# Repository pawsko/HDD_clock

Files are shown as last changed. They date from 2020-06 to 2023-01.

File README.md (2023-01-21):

# My first embedded project #
## Introduction ##
Some time ago I saw an amazing clock based on HDD on Youtube. There was dedicated clock face made from original plate with drilled numbers
from 0 to 9 and colon sign. Under plate there were LEDs. Clock face was rotating very fast, exactly 5400RPM like regular HDD. LEDs were blinked
exectly right in time when right number was above right LED. I was thinking this project is perfect to replicate for my self and practise C programming:)
Clock which I saw had only hours and minutes. I wanted to go a step further and add seconds as well.

It took me some of time to figure out how to approach to this topic.
The easiest part for me was design hardware. I took broken HDD, removed all platters, measured their diameters and made a decision that there will be 
12 signs on PCB.
Why 12? because of dividing. 

360 degrees / 11 signs = 32.72727272.... degrees per sign

360 / 12 = 30 degrees per sign. Very nice.

I wasn't shure about shape of controller, so I split electronics to two part. Controller and LED driver. I planned to use evaluation board 
with FPGA or microcontroller on board and design only board with LED, power supply circuits and buttons. 
FPGA is obvoius for this solution but I have no knowledge and experience in this area.
## First version (prototype) ##
In first attempt I used NUCLEO-F103RB. Cheap and very popular evaluation board with STM32F103 microcontroller. I utylized there all counters. 
Each digit has own. One additional counter measures one complete revolution.
There is an interrupt for detect zero position of clock face.
Brushless motor controller was taken from HDD so it spinup motor only for 10 second and expected signal from magnetic heads (were removed). Additionally once per second reduced speed for a while.
Despite this it worked. After 10 seconds motor has stopped. Probably disk controller reported error to host (BIOS in PC).
There was some issue with synchronisation while colons were blinked.
## Second version ##
I integrated two parts of electronics to one board and I added Real Time Clock programmed through UART with backup battery, brushless motor controller,
button to change mode clock/callendar (last video). I changed soldermask from regular green to black (looks like dark brown).
## Opened issues ##
1. Unfortunatelly motor is noisy.
2. Contrast is insufficient during sunlight. LEDs are super bright but clock face builded from FR4 provides low light transmision. Second wersion with black solder mask is much more effective, but it's still not enough.
3. Clock face is unbalanced because of heteregenous material and digits. Reminder: 5400RPM.
4. Best effect is in the dark room (at night) but take a look at point one :(

## Photos ##
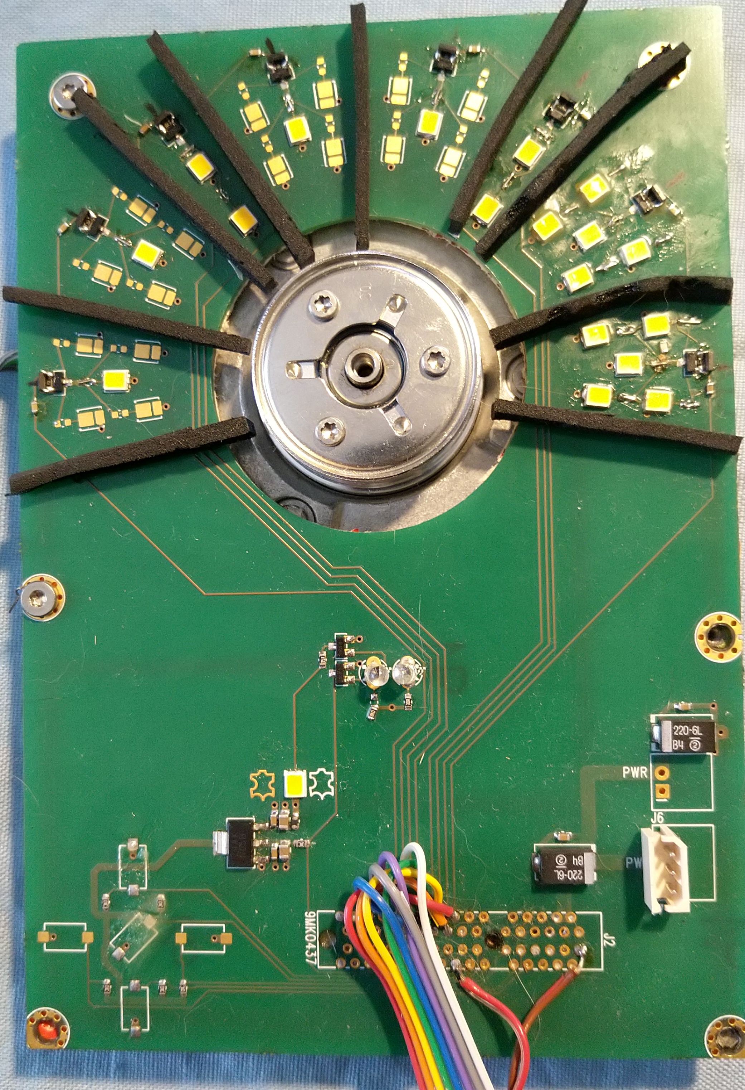
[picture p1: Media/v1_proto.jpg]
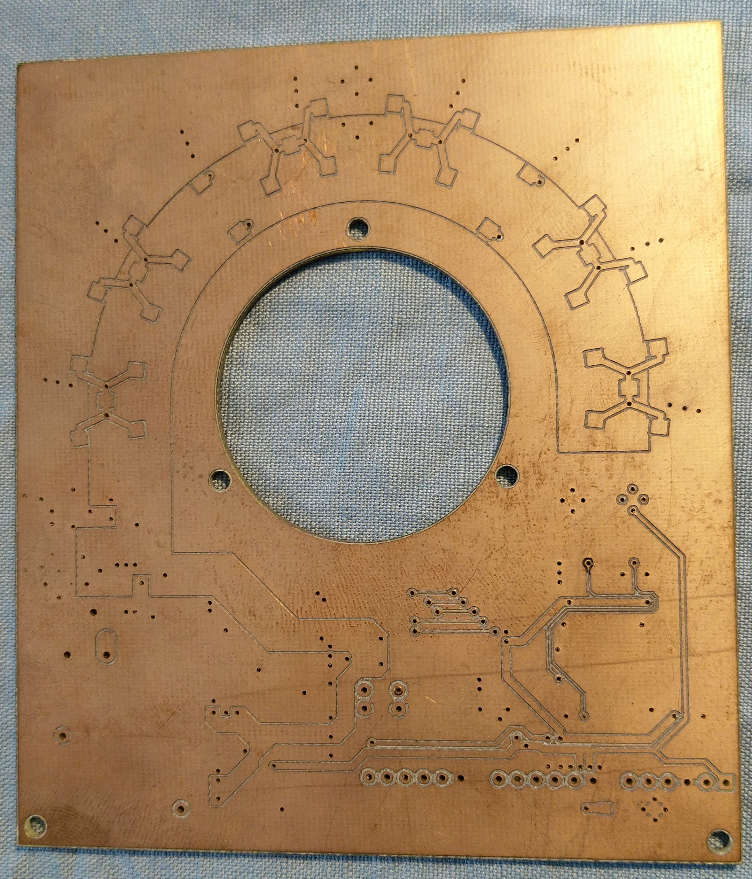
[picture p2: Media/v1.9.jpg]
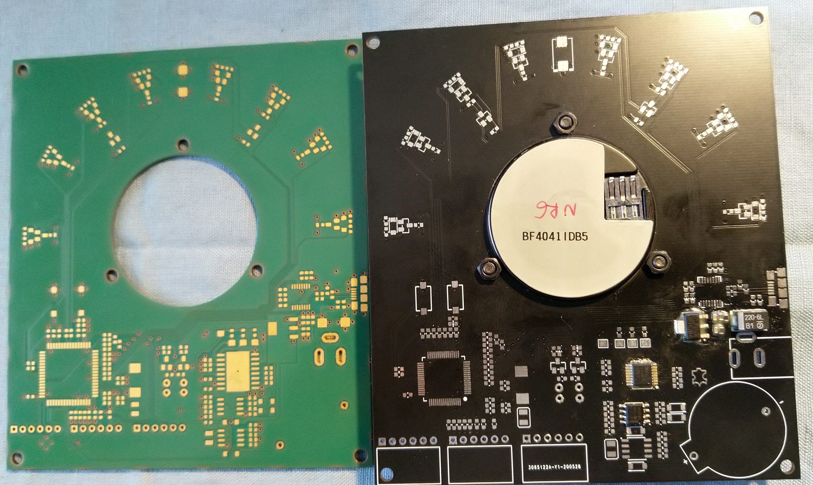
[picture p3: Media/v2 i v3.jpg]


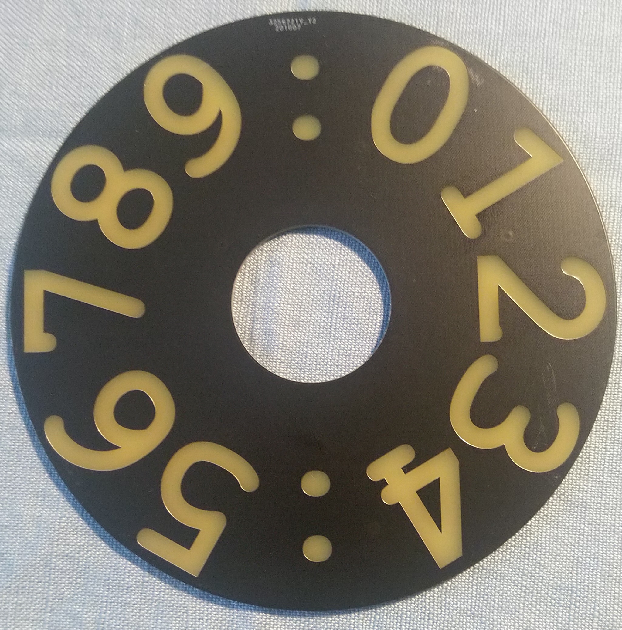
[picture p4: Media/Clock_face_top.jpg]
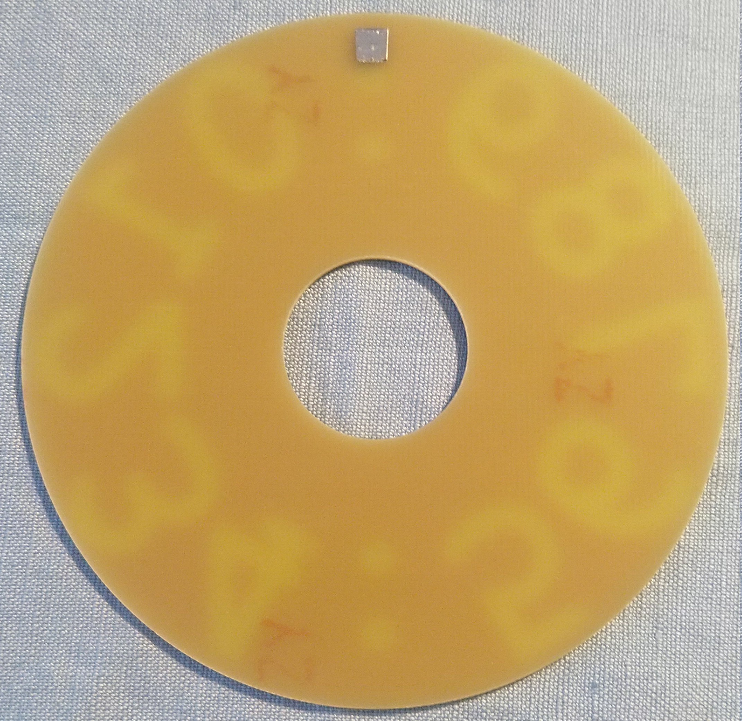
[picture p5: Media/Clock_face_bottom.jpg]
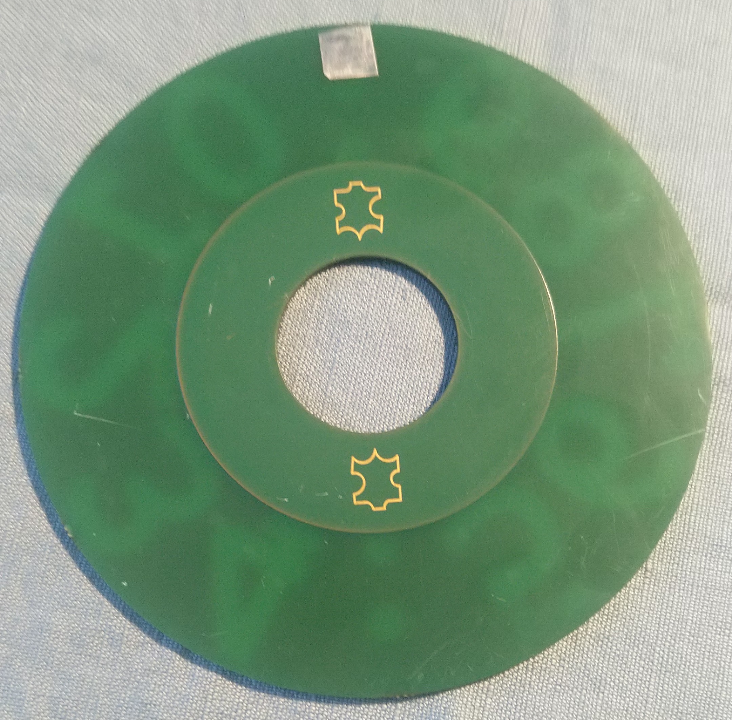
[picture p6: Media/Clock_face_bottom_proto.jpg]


## Links to short video ##
https://youtube.com/shorts/ItIJTu948P8

https://youtube.com/shorts/eFmTAhwEkuo

V2 with old clock face. 

https://www.youtube.com/watch?v=KfqW7rv5enw

## Titbit ##
How much do mistakes cost??

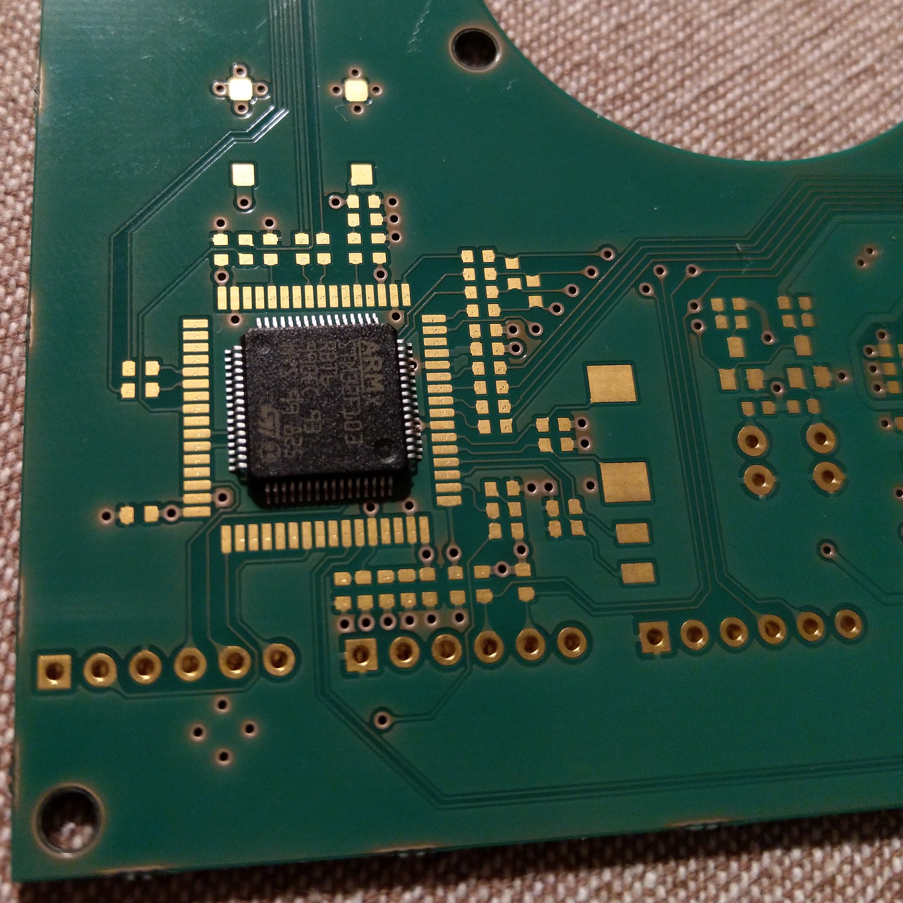
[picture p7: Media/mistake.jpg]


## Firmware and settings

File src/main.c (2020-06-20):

/**
  ******************************************************************************
  * @file    main.c
  * @author  Ac6
  * @version V1.0
  * @date    01-December-2013
  * @brief   Default main function.
  ******************************************************************************
*/

#include "stdio.h"
//#include <stdio.h>
#include "stm32f10x.h"

//dynamic rotated count

uint32_t SysTick_Config_Mod(uint32_t SysTick_CLKSource, uint32_t Ticks);

uint16_t delay = 24;    //this value gives 25,48us
uint16_t strob = 7306;
uint16_t sysTick1Ms = 0;
uint8_t sysTick100Ms = 0;
uint32_t step = 0;
uint16_t fullSpin;
uint8_t task100ms = 0;    //0-ready to do; 1-done
uint8_t task1ms = 0;    //0-ready to do; 1-done
uint8_t newSpin = 0;    //0-end spin detection

//default displayed hour after reset

uint8_t hourDecade = 0;    //hour10
uint8_t hourUnit = 0;    //hour1
uint8_t minuteDecade = 0;    //minute10
uint8_t minuteUnit = 0;    //minute1
uint8_t secondDecade = 0;    //second10
uint8_t secondUnit = 0;    //second1

char colonToggle = 0;    //respond for symbol ":"

uint16_t hour10 = 9133;
uint16_t hour1 = 8220;
uint16_t colonHoursMinutes = 1142;
uint16_t minute10 = 6850;
uint16_t minute1 = 5937;
uint16_t colonMinutesSeconds = 9818;
uint16_t second10 = 4567;
uint16_t second1 = 3653;

int main(void)
{
  initUart();
  initI2cForRtc();
  printf("HDD Clock by Pawsko\r\n");
  readRtc();

  RCC_APB1PeriphClockCmd(RCC_APB1Periph_USART2, ENABLE);    //start USART
  RCC_APB1PeriphClockCmd(RCC_APB1Periph_TIM2 | RCC_APB1Periph_TIM3 | RCC_APB1Periph_TIM4, ENABLE);    //TIMER 2, 3 i 4 started
  RCC_APB2PeriphClockCmd(RCC_APB2Periph_GPIOA | RCC_APB2Periph_AFIO, ENABLE);    //port A started (interrupt, uart, LED)
  RCC_APB2PeriphClockCmd(RCC_APB2Periph_GPIOC, ENABLE);    //Port C started: Strobs for LED

  GPIO_InitTypeDef gpio;
  //USART_InitTypeDef uart;
  NVIC_InitTypeDef nvic;
  TIM_TimeBaseInitTypeDef tim;
  TIM_ICInitTypeDef ictim;
  TIM_OCInitTypeDef octim;

  GPIO_StructInit(&gpio);    //Interrupt from  clock table ZERO position
  gpio.GPIO_Pin = GPIO_Pin_1;
  gpio.GPIO_Mode = GPIO_Mode_IN_FLOATING;
  gpio.GPIO_Speed = GPIO_Speed_50MHz;
  GPIO_Init(GPIOA, &gpio);

  //GPIO_StructInit(&gpio);    //UART2 - TX
  gpio.GPIO_Pin = GPIO_Pin_2;
  gpio.GPIO_Mode = GPIO_Mode_AF_PP;
  GPIO_Init(GPIOA, &gpio);

  //GPIO_StructInit(&gpio);    //UART2 - RX
  gpio.GPIO_Pin = GPIO_Pin_3;
  gpio.GPIO_Mode = GPIO_Mode_IN_FLOATING;
  GPIO_Init(GPIOA, &gpio);

  //GPIO_StructInit(&gpio);    //Green LED on Nucleo board "hearbeat"
  gpio.GPIO_Pin = GPIO_Pin_5;
  gpio.GPIO_Mode = GPIO_Mode_Out_PP;
  GPIO_Init(GPIOA, &gpio);

  //Strobed LED
  gpio.GPIO_Pin = GPIO_Pin_0 | GPIO_Pin_1 | GPIO_Pin_2 | GPIO_Pin_3 | GPIO_Pin_4 | GPIO_Pin_5 | GPIO_Pin_6 | GPIO_Pin_7;
  gpio.GPIO_Mode = GPIO_Mode_Out_PP;
  GPIO_Init(GPIOC, &gpio);

  nvic.NVIC_IRQChannel = TIM2_IRQn;    //Timer_2 general interrupt config
  nvic.NVIC_IRQChannelPreemptionPriority = 0;    //count one rotate time
  nvic.NVIC_IRQChannelSubPriority = 1;
  nvic.NVIC_IRQChannelCmd = ENABLE;
  NVIC_Init(&nvic);

  nvic.NVIC_IRQChannel = TIM3_IRQn;    //Timer_3 general interrupt config
  nvic.NVIC_IRQChannelPreemptionPriority = 1;    //Strob for: 10 hours; 1 hour; ":" between hours and minutes; ten minutes
  nvic.NVIC_IRQChannelSubPriority = 1;
  nvic.NVIC_IRQChannelCmd = ENABLE;
  NVIC_Init(&nvic);

  nvic.NVIC_IRQChannel = TIM4_IRQn;    // Timer_4 general intterupt config
  nvic.NVIC_IRQChannelPreemptionPriority = 1;    //Strob for 1 minute; ":" between minutes and seconds; 10 seconds; 1 second
  nvic.NVIC_IRQChannelSubPriority = 1;
  nvic.NVIC_IRQChannelCmd = ENABLE;
  NVIC_Init(&nvic);

  TIM_TimeBaseStructInit(&tim);    //This counter count one rotate of clock table
  tim.TIM_CounterMode = TIM_CounterMode_Up;
  tim.TIM_Period = 65535;    //1us * 65535 = 65ms 535us
  tim.TIM_Prescaler = 64;    //fclk=64Mhz/64000=1MHz
  tim.TIM_ClockDivision = 0;
  TIM_TimeBaseInit(TIM2, &tim);

  TIM_ICStructInit(&ictim);    //Timer_2 config input capture, zero position detection
  ictim.TIM_Channel = TIM_Channel_2;
  ictim.TIM_ICPolarity = TIM_ICPolarity_Rising;
  ictim.TIM_ICSelection = TIM_ICSelection_DirectTI;
  ictim.TIM_ICPrescaler = TIM_ICPSC_DIV1;
  ictim.TIM_ICFilter = 0;
  TIM_ICInit(TIM2, &ictim);

  tim.TIM_CounterMode = TIM_CounterMode_Up;    //Timer_3 config for LED strobes
  tim.TIM_Prescaler = 64;
  tim.TIM_Period = 65535;
  TIM_TimeBaseInit(TIM3, &tim);

  tim.TIM_CounterMode = TIM_CounterMode_Up;    //Timer_4 config for LED strobes
  tim.TIM_Prescaler = 64;
  tim.TIM_Period = 65535;
  TIM_TimeBaseInit(TIM4, &tim);

  //Timer_3 channel 1 config
  octim.TIM_OCMode = TIM_OCMode_Timing;    //mode
  octim.TIM_OutputState = TIM_OutputState_Enable;    //Enable output
  octim.TIM_Pulse = hour10;    //hour10 pulses
  TIM_OC1Init(TIM3, &octim);   //Channel 1 initialization

  //Timer_3 channel 2 config
  octim.TIM_OCMode = TIM_OCMode_Timing;    //mode
  octim.TIM_OutputState = TIM_OutputState_Enable;    //Enable output
  octim.TIM_Pulse = hour1;    //hour1 pulses
  TIM_OC2Init(TIM3, &octim);   //Channel 2 initialization

  //Timer_3 channel 3 config
  octim.TIM_OCMode = TIM_OCMode_Timing;    //mode
  octim.TIM_OutputState = TIM_OutputState_Enable;    //Enable output
  octim.TIM_Pulse = colonHoursMinutes;    //colonHoursMinutes pulses
  TIM_OC3Init(TIM3, &octim);   //Channel 3 initialization

  //Timer_3 channel 4 config
  octim.TIM_OCMode = TIM_OCMode_Timing;    //mode
  octim.TIM_OutputState = TIM_OutputState_Enable;    //Enable output
  octim.TIM_Pulse = minute10;    //minute10 pulses
  TIM_OC4Init(TIM3, &octim);   //Channel 4 initialization

  //Timer_4 channel 1 config
  octim.TIM_OCMode = TIM_OCMode_Timing;    //mode
  octim.TIM_OutputState = TIM_OutputState_Enable;    //Enable output
  octim.TIM_Pulse = minute1;    //minute1 pulses
  TIM_OC1Init(TIM4, &octim);   //Channel 1 initialization

  //Timer_4 channel 2 config
  octim.TIM_OCMode = TIM_OCMode_Timing;    //mode
  octim.TIM_OutputState = TIM_OutputState_Enable;    //Enable output
  octim.TIM_Pulse = colonMinutesSeconds;    //colonMinutesSeconds pulses
  TIM_OC2Init(TIM4, &octim);   //Channel 2 initialization

  //Timer_4 channel 3 config
  octim.TIM_OCMode = TIM_OCMode_Timing;    //mode
  octim.TIM_OutputState = TIM_OutputState_Enable;    //Enable output
  octim.TIM_Pulse = second10;    //second10 pulses
  TIM_OC3Init(TIM4, &octim);   //Channel 3 initialization

  //Timer_4 channel 4 config
  octim.TIM_OCMode = TIM_OCMode_Timing;    //mode
  octim.TIM_OutputState = TIM_OutputState_Enable;    //Enable output
  octim.TIM_Pulse = second1;    //second1 pulses
  TIM_OC4Init(TIM4, &octim);   //Channel 4 initialization

  TIM_ITConfig(TIM2, TIM_IT_CC2, ENABLE);
  TIM_Cmd(TIM2, ENABLE);    //Start Timer TIM2

  TIM_ITConfig(TIM3, TIM_IT_CC1 | TIM_IT_CC2 | TIM_IT_CC3 | TIM_IT_CC4, ENABLE);    //Enable interrupt from Timer 2 from Clock Capture 1, 2, 3, 4
  TIM_Cmd(TIM3, ENABLE);    //Start Timer TIM3

  TIM_ITConfig(TIM4, TIM_IT_CC1 | TIM_IT_CC2 | TIM_IT_CC3 | TIM_IT_CC4, ENABLE);    //Enable interrupt from Timer 3 from Clock Capture 1, 2, 3, 4
  TIM_Cmd(TIM4, ENABLE);    //Start Timer TIM4

  GPIO_ResetBits(GPIOC, GPIO_Pin_0 | GPIO_Pin_1 | GPIO_Pin_2 | GPIO_Pin_3 | GPIO_Pin_4 | GPIO_Pin_5 | GPIO_Pin_6 | GPIO_Pin_7 | GPIO_Pin_9);

  if (SysTick_Config_Mod(SysTick_CLKSource_HCLK_Div8, 8000ul))
  {
    while(1)    // infinity loop in error case
    {
    }
  }

  while(1)
  {

    if (sysTick100Ms == 0 && task100ms == 0)    //every seconds
    {
      if ((secondDecade == 5) && (secondUnit == 10))    //If seconds = 60
      {
        secondUnit = 0;
        secondDecade = 0;
        minuteUnit++;    //increment minutes units
      }

      if (secondUnit == 10)    //If seconds = 10
      {
        secondUnit = 0;
        secondDecade++;          //increment seconds decade
      }

      if ((minuteDecade == 5) && (minuteUnit == 10))    //If minutes = 60
      {
        minuteUnit = 0;
        minuteDecade = 0;
        hourUnit++;    //increment hours units
      }

      if (minuteUnit == 10)    //If minutes = 10
      {
        minuteUnit = 0;
        minuteDecade++;    //increment minutes decade
      }

      if ((hourDecade == 2) && (hourUnit == 4))    //if hours = 24 reset decade and unit hours
      {
        hourUnit = 0;
        hourDecade = 0;
      }

      if (hourUnit == 10)    //If hours = 10
      {
        hourUnit = 0;
        hourDecade++;    //increment hours decade
      }
      if (colonToggle == 0)
        {
          colonToggle++;
        }
        else
        {
          colonToggle = 0;
        }
      task100ms = 1;
    }

    if (newSpin == 0)    //every each finished rotate
    {
      switch (hourDecade){    //hours decade
      case 0:
      {
        hour10 = fullSpin * 10 / 12;
        break;
      }
      case 1:
      {
        hour10 = fullSpin * 11 / 12;
        break;
      }
      case 2:
      {
        hour10 = 0;
        break;
      }
      default:
      {
      break;
      }
      }

      switch (hourUnit){    //hours units
      case 0:
      {
        hour1 = fullSpin * 9 / 12;
        break;
      }
      case 1:
      {
        hour1 = fullSpin * 10 / 12;
        break;
      }
      case 2:
      {
        hour1 = fullSpin * 11 / 12;
        break;
      }
      case 3:
      {
        hour1 = 0;
        break;
      }
      case 4:
      {
        hour1 = fullSpin * 1 / 12;
        break;
      }
      case 5:
      {
        hour1 = fullSpin * 3 / 12;
        break;
      }
      case 6:
      {
        hour1 = fullSpin * 4 / 12;
        break;
      }
      case 7:
      {
        hour1 = fullSpin * 5 / 12;
        break;
      }
      case 8:
      {
        hour1 = fullSpin * 6 / 12;
        break;
      }
      case 9:
      {
        hour1 = fullSpin * 7 / 12;
        break;
      }
      default:
      {
        break;
      }
      }

      switch (minuteDecade){    //minutes decades
      case 0:
      {
        minute10 = fullSpin * 15 / 24;
        break;
      }
      case 1:
      {
        minute10 = fullSpin * 17 / 24;
        break;
      }
      case 2:
      {
        minute10 = fullSpin * 19 / 24;
        break;
      }
      case 3:
      {
        minute10 = fullSpin * 21 / 24;
        break;
      }
      case 4:
      {
        minute10 = fullSpin * 23 / 24;
        break;
      }
      case 5:
      {
        minute10 = fullSpin * 3 / 24;
        break;
      }
      case 6:
      {
        minute10 = fullSpin * 5 / 24;
        break;
      }
      case 7:
      {
        minute10 = fullSpin * 71 / 24;
        break;
      }
      case 8:
      {
        minute10 = fullSpin * 9 / 24;
        break;
      }
      case 9:
      {
        minute10 = fullSpin * 11 / 24;
        break;
      }
      default:
      {
        break;
      }
      }

      switch (minuteUnit){    //minutes units
      case 0:
      {
        minute1 = fullSpin * 13 / 24;
        break;
      }
      case 1:
      {
        minute1 = fullSpin * 15 / 24;
        break;
      }
      case 2:
      {
        minute1 = fullSpin * 17 / 24;
        break;
      }
      case 3:
      {
        minute1 = fullSpin * 19 / 24;
        break;
      }
      case 4:
      {
        minute1 = fullSpin * 21 / 24;
        break;
      }
      case 5:
      {
        minute1 = fullSpin * 1 / 24;
        break;
      }
      case 6:
      {
        minute1 = fullSpin * 3 / 24;
        break;
      }
      case 7:
      {
        minute1 = fullSpin * 5 / 24;
        break;
      }
      case 8:
      {
        minute1 = fullSpin * 7 / 24;
        break;
      }
      case 9:
      {
        minute1 = fullSpin * 9 / 24;
        break;
      }
      default:
      {
        break;
      }
      }

      switch (secondDecade){    //seconds decades
      case 0:
      {
        second10 = fullSpin * 5 / 12;
        break;
      }
      case 1:
      {
        second10 = fullSpin * 6 / 12;
        break;
      }
      case 2:
      {
        second10 = fullSpin * 7 / 12;
        break;
      }
      case 3:
      {
        second10 = fullSpin *8 / 12;
        break;
      }
      case 4:
      {
        second10 = fullSpin * 9 / 12;
        break;
      }
      case 5:
      {
        second10 = fullSpin * 11 / 12;
        break;
      }
      case 6:
      {
        second10 = 0;
        break;
      }
      case 7:
      {
        second10 = fullSpin * 1 / 12;
        break;
      }
      case 8:
      {
        second10 = fullSpin * 2 / 12;
        break;
      }
      case 9:
      {
        second10 = fullSpin * 3 / 12;
        break;
      }
      default:
      {
        break;
      }
      }

      switch (secondUnit){    //seconds units
      case 0:
      {
        second1 = fullSpin * 4 / 12;
        break;
      }
      case 1:
      {
        second1 = fullSpin * 5 / 12;
        break;
      }
      case 2:
      {
        second1 = fullSpin * 6 / 12;
        break;
      }
      case 3:
      {
        second1 = fullSpin * 7 / 12;
        break;
      }
      case 4:
      {
        second1 = fullSpin * 8 / 12;
        break;
      }
      case 5:
      {
        second1 = fullSpin * 10 / 12;
        break;
      }
      case 6:
      {
        second1 = fullSpin * 11 / 12;
        break;
      }
      case 7:
      {
        second1 = 0;
        break;
      }
      case 8:
      {
        second1 = fullSpin * 1 / 12;
        break;
      }
      case 9:
      {
        second1 = fullSpin * 2 / 12;
        break;
      }
      default:
      {
        break;
      }
      }

      colonHoursMinutes = fullSpin * 5 /48;
      colonMinutesSeconds = fullSpin * 19 /48;

      TIM_OCInitTypeDef octim;

      //Timer_3 1st channel config
      octim.TIM_OCMode = TIM_OCMode_Timing;    //mode
      octim.TIM_OutputState = TIM_OutputState_Enable;    //Enable outputs
      octim.TIM_Pulse = hour10;    //hour10 pulses
      TIM_OC1Init(TIM3, &octim);   //1st channel initialization

      //Timer_3 2nd channel config
      octim.TIM_OCMode = TIM_OCMode_Timing;    //mode
      octim.TIM_OutputState = TIM_OutputState_Enable;    //Enable outputs
      octim.TIM_Pulse = hour1;    //hour1 pulses
      TIM_OC2Init(TIM3, &octim);    //2nd channel initialization

      //Timer_3 3rd channel config
      octim.TIM_OCMode = TIM_OCMode_Timing;    //tryb pracy kanalu
      octim.TIM_OutputState = TIM_OutputState_Enable;    //Enable outputs
      octim.TIM_Pulse = colonHoursMinutes;  //colonHoursMinutes pulses
      TIM_OC3Init(TIM3, &octim);   //3rd channel initialization

      ////Timer_3 4th channel config
      octim.TIM_OCMode = TIM_OCMode_Timing;    //mode
      octim.TIM_OutputState = TIM_OutputState_Enable;    //Enable outputs
      octim.TIM_Pulse = minute10;    //minute10 pulses
      TIM_OC4Init(TIM3, &octim);   //4th channel initialization

      //Timer_4 1st channel config
      octim.TIM_OCMode = TIM_OCMode_Timing;    //mode
      octim.TIM_OutputState = TIM_OutputState_Enable;    //Enable outputs
      octim.TIM_Pulse = minute1;  //minute1 pulses
      TIM_OC1Init(TIM4, &octim);    //1st channel initialization

      //Timer_4 2nd channel config
      octim.TIM_OCMode = TIM_OCMode_Timing;    //mode
      octim.TIM_OutputState = TIM_OutputState_Enable;    //Enable outputs
      octim.TIM_Pulse = colonMinutesSeconds;  //colonMinutesSeconds pulses
      TIM_OC2Init(TIM4, &octim);    //2nd channel initialization


      //Timer_4 3rd channel config
      octim.TIM_OCMode = TIM_OCMode_Timing;    //mode
      octim.TIM_OutputState = TIM_OutputState_Enable;    //Enable outputs
      octim.TIM_Pulse = second10;    //colonHoursMinutes pulses
      TIM_OC3Init(TIM4, &octim);    //3rd channel initialization

      //Timer_4 4th channel config
      octim.TIM_OCMode = TIM_OCMode_Timing;    //mode
      octim.TIM_OutputState = TIM_OutputState_Enable;    //Enable outputs
      octim.TIM_Pulse = second1;  //second10 pulses
      TIM_OC4Init(TIM4, &octim);   //4th channel initialization

      newSpin = 1;

    }
  }

}

void SysTick_Handler(void)
{
  sysTick1Ms++;
  if (sysTick1Ms == 100)
  {
    sysTick100Ms++;
    sysTick1Ms = 0;
    task1ms = 0;
  }
  if (sysTick100Ms == 10)
  {
    secondUnit++;
    sysTick100Ms = 0;
    task100ms = 0;
    GPIO_WriteBit(GPIOA, GPIO_Pin_5, (BitAction)(1-GPIO_ReadOutputDataBit(GPIOA, GPIO_Pin_5)));
  }

}

uint32_t  SysTick_Config_Mod(uint32_t SysTick_CLKSource, uint32_t Ticks)
{
  //SysTick initialization
  uint32_t Settings;

  assert_param(IS_SYSTICK_CLK_SOURCE(SysTick_CLKSource));

  if (Ticks > SysTick_LOAD_RELOAD_Msk)  return (1);    //Kontrola, czy wartosc poczatkowa nie przekracza max

  SysTick->LOAD = (Ticks & SysTick_LOAD_RELOAD_Msk) - 1;  //Set timer start value
  NVIC_SetPriority (SysTick_IRQn, 0);   //set interrupt priority
  SysTick->VAL  = 0;  //Set value
  Settings=SysTick_CTRL_TICKINT_Msk | SysTick_CTRL_ENABLE_Msk;
  if (SysTick_CLKSource == SysTick_CLKSource_HCLK)
  {
    Settings |= SysTick_CLKSource_HCLK;
  }
  else
  {
    Settings &= SysTick_CLKSource_HCLK_Div8;
  }
  SysTick->CTRL = Settings;    //Save settings to SysTick register and switch on timer
  return (0);
}

void TIM2_IRQHandler(void)
{
  if (TIM_GetITStatus(TIM2, TIM_IT_Update) == SET)
  {
    TIM_ClearITPendingBit(TIM2, TIM_IT_Trigger);
  }
  if (TIM_GetITStatus(TIM2, TIM_IT_CC2) == SET)    //If interrupt from 2nd channel
  {
    TIM_ClearITPendingBit(TIM2, TIM_IT_CC2);    //reset interrupt flag

    fullSpin = TIM_GetCapture2(TIM2);    //Read register CCR value for 2nd channel
    TIM_SetCounter(TIM2, 0);    //Timer_2 reset
    TIM_SetCounter(TIM3, 0);    //Timer_3 reset
    TIM_SetCounter(TIM4, 0);    //Timer_4 reset
    GPIO_ResetBits(GPIOC, GPIO_Pin_0 | GPIO_Pin_1 | GPIO_Pin_2 | GPIO_Pin_3 | GPIO_Pin_4 | GPIO_Pin_5 | GPIO_Pin_6 | GPIO_Pin_7);
    newSpin = 0;
  }
}

void TIM3_IRQHandler(void)
{
  if (TIM_GetITStatus(TIM3, TIM_IT_Update) == SET)   //if interrupt from Timer_3 event
  {
    TIM_ClearITPendingBit(TIM3, TIM_IT_Update);     //reset interrupt flag
  }
  if (TIM_GetITStatus(TIM3, TIM_IT_CC1) != RESET)  {    //value from CC1 is achieved
    TIM_ClearITPendingBit(TIM3, TIM_IT_CC1);
    GPIO_SetBits(GPIOC, GPIO_Pin_0);
  }
  if (TIM_GetITStatus(TIM3, TIM_IT_CC2) != RESET)  {    //value from CC2 is achieved
    TIM_ClearITPendingBit(TIM3, TIM_IT_CC2);
    GPIO_SetBits(GPIOC, GPIO_Pin_1);
  }
  if (TIM_GetITStatus(TIM3, TIM_IT_CC3) != RESET)  {    //value from CC3 is achieved
    TIM_ClearITPendingBit(TIM3, TIM_IT_CC3);
    if (colonToggle == 1)
    {
      GPIO_SetBits(GPIOC, GPIO_Pin_2);
    }
  }
  if (TIM_GetITStatus(TIM3, TIM_IT_CC4) != RESET)  {    //value from CC4 is achieved
    TIM_ClearITPendingBit(TIM3, TIM_IT_CC4);
    GPIO_SetBits(GPIOC, GPIO_Pin_3);
  }
}

void TIM4_IRQHandler(void)
{
  if (TIM_GetITStatus(TIM4, TIM_IT_Update) == SET)   //if interrupt from Timer_4 event
  {
    TIM_ClearITPendingBit(TIM4, TIM_IT_Update);    //reset interrupt flag
  }
  if (TIM_GetITStatus(TIM4, TIM_IT_CC1) != RESET)  {    //value from CC1 is achieved
    TIM_ClearITPendingBit(TIM4, TIM_IT_CC1);
    GPIO_SetBits(GPIOC, GPIO_Pin_4);
  }
  if (TIM_GetITStatus(TIM4, TIM_IT_CC2) != RESET)  {    //value from CC2 is achieved
    TIM_ClearITPendingBit(TIM4, TIM_IT_CC2);
    if (colonToggle == 1)
    {
      GPIO_SetBits(GPIOC, GPIO_Pin_5);
    }
  }
  if (TIM_GetITStatus(TIM4, TIM_IT_CC3) != RESET)  {    //value from CC3 is achieved
    TIM_ClearITPendingBit(TIM4, TIM_IT_CC3);
    GPIO_SetBits(GPIOC, GPIO_Pin_6);
  }
  if (TIM_GetITStatus(TIM4, TIM_IT_CC4) != RESET)  {    //value from CC4 is achieved
    TIM_ClearITPendingBit(TIM4, TIM_IT_CC4);
    GPIO_SetBits(GPIOC, GPIO_Pin_7);
  }
}

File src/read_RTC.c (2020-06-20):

/*
 * readRtc.c
 *
 *  Created on: 01.01.2019
 *      Author: DJPifPaf
 */

#include "stm32f10x.h"

extern uint8_t hourDecade;
extern uint8_t hourUnit;
extern uint8_t minuteDecade;
extern uint8_t minuteUnit;
extern uint8_t secondDecade;
extern uint8_t secondUnit;

void initI2cForRtc(void)
{
  GPIO_InitTypeDef gpio;
  I2C_InitTypeDef i2c;

  RCC_APB2PeriphClockCmd(RCC_APB2Periph_GPIOA | RCC_APB2Periph_GPIOB | RCC_APB2Periph_GPIOC | RCC_APB2Periph_GPIOD, ENABLE);
  RCC_APB2PeriphClockCmd(RCC_APB2Periph_AFIO, ENABLE);
  RCC_APB1PeriphClockCmd(RCC_APB1Periph_I2C1, ENABLE);

  GPIO_StructInit(&gpio);
  gpio.GPIO_Pin = GPIO_Pin_6|GPIO_Pin_7; // SCL, SDA
  gpio.GPIO_Mode = GPIO_Mode_AF_OD;
  gpio.GPIO_Speed = GPIO_Speed_50MHz;
  GPIO_Init(GPIOB, &gpio);

  I2C_SoftwareResetCmd(I2C1, ENABLE);
  I2C_SoftwareResetCmd(I2C1, DISABLE);
  I2C_StructInit(&i2c);
  i2c.I2C_Mode = I2C_Mode_I2C;
  i2c.I2C_Ack = I2C_Ack_Enable;
  i2c.I2C_ClockSpeed = 100000;
  I2C_Init(I2C1, &i2c);
  I2C_Cmd(I2C1, ENABLE);

}

void readRtc(void)
{
  I2C_GenerateSTART(I2C1, ENABLE);    //Start
  while (I2C_CheckEvent(I2C1, I2C_EVENT_MASTER_MODE_SELECT) != SUCCESS);

  I2C_Send7bitAddress(I2C1, 0xD0, I2C_Direction_Transmitter);    //Write to address 0xD0
  while (I2C_CheckEvent(I2C1, I2C_EVENT_MASTER_TRANSMITTER_MODE_SELECTED) != SUCCESS);

  I2C_SendData(I2C1, 0x00);    //Set address to 0x00
  while (I2C_CheckEvent(I2C1, I2C_EVENT_MASTER_BYTE_TRANSMITTING) != SUCCESS);

  I2C_GenerateSTART(I2C1, ENABLE);
  while (I2C_CheckEvent(I2C1, I2C_EVENT_MASTER_MODE_SELECT) != SUCCESS);    //Start

  I2C_AcknowledgeConfig(I2C1, ENABLE);
  I2C_Send7bitAddress(I2C1, 0xD0, I2C_Direction_Receiver);    //read first cell
  while (I2C_CheckEvent(I2C1, I2C_EVENT_MASTER_RECEIVER_MODE_SELECTED) != SUCCESS);

  while(I2C_CheckEvent(I2C1, I2C_EVENT_MASTER_BYTE_RECEIVED) != SUCCESS);
  uint8_t data0 = I2C_ReceiveData(I2C1);

  I2C_AcknowledgeConfig(I2C1, ENABLE);
  while(I2C_CheckEvent(I2C1, I2C_EVENT_MASTER_BYTE_RECEIVED) != SUCCESS);
  uint8_t data1 = I2C_ReceiveData(I2C1);

  I2C_AcknowledgeConfig(I2C1, ENABLE);
  while(I2C_CheckEvent(I2C1, I2C_EVENT_MASTER_BYTE_RECEIVED) != SUCCESS);
  uint8_t data2 = I2C_ReceiveData(I2C1);

/* DAY OF WEEK */
  I2C_AcknowledgeConfig(I2C1, ENABLE);
  while(I2C_CheckEvent(I2C1, I2C_EVENT_MASTER_BYTE_RECEIVED) != SUCCESS);
  uint8_t data3 = I2C_ReceiveData(I2C1);

  I2C_AcknowledgeConfig(I2C1, ENABLE);
  while(I2C_CheckEvent(I2C1, I2C_EVENT_MASTER_BYTE_RECEIVED) != SUCCESS);
  uint8_t data4 = I2C_ReceiveData(I2C1);

  I2C_AcknowledgeConfig(I2C1, ENABLE);
  while(I2C_CheckEvent(I2C1, I2C_EVENT_MASTER_BYTE_RECEIVED) != SUCCESS);
  uint8_t data5 = I2C_ReceiveData(I2C1);

  I2C_AcknowledgeConfig(I2C1, ENABLE);
  while(I2C_CheckEvent(I2C1, I2C_EVENT_MASTER_BYTE_RECEIVED) != SUCCESS);
  uint8_t data6 = I2C_ReceiveData(I2C1);

  I2C_AcknowledgeConfig(I2C1, DISABLE);
  I2C_GenerateSTOP(I2C1, ENABLE);
  while(I2C_CheckEvent(I2C1, I2C_EVENT_MASTER_BYTE_RECEIVED) != SUCCESS);
  uint8_t data7 = I2C_ReceiveData(I2C1);
  //I2C_AcknowledgeConfig(I2C1, ENABLE);

  /* SECONDS */

  uint8_t tenSec = 0x70 & data0;
  tenSec >>= 4;
  uint8_t sec = 0x0F & data0;

  secondDecade = tenSec;
  secondUnit = sec;

  /* MINUTES */

  uint8_t tenMin = 0x70 & data1;
  tenMin >>= 4;
  uint8_t min = 0x0F & data1;

  minuteDecade = tenMin;
  minuteUnit = min;

  /* HOURS */

  printf("DATA2 RAW %x\r\n", data2);
  printf("DATA7 RAW %x\r\n", data7);
  uint8_t typeOfClock = 0X40 & data2;
  typeOfClock >>= 3;

  uint8_t tenHrs;
  hourDecade = tenHrs;

  int8_t amPm;

  /* DAY OF MONTH */

  uint8_t tenDays = 0x50 & data4;
  tenDays >>= 4;
  uint8_t days = 0x0F & data4;
  printf("Day: %d \r\n", data3);

  /* MONTH */
  uint8_t tenMonths = 0x10 & data5;
  tenMonths >>= 4;
  uint8_t months = 0x0F & data5;

  /* YEAR */
  uint8_t tenYears = 0xF0 & data6;
  tenYears >>= 4;
  uint8_t years = 0x0F & data6;

  if (typeOfClock == ENABLE) // 12h clock AM and PM
  {
    tenHrs = 0x10 & data2;
    tenHrs >>= 4;
  }
  else
  {
    tenHrs = 0x30 & data2;
    tenHrs >>= 4;
  }

  uint8_t hrs = 0x0F & data2;

  hourDecade = tenHrs;
  hourUnit = hrs;

  printf("Time: %d%d:%d%d:%d%d", tenHrs, hrs, tenMin, min, tenSec, sec);
  if (typeOfClock == ENABLE) // 12h clock AM and PM
  {
   amPm = 0x20 & data2;
   amPm >>= 4;
    if (amPm == DISABLE) // means AM
    {
      printf(" AM\r\n");
    }
    else
    {
      printf(" PM\r\n");
    }
  }

  printf("\r\n");
  printf("Data: %d%d.%d%d.%d%d\r\n", tenDays, days, tenMonths, months, tenYears, years);
}

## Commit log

2019-02-09 first cosmetics inprovement
    [Clock_02_HH_display Run.cfg]
2019-02-13 fixed name of variables
    [main.c, read_RTC.c]
2019-02-13 fixed name of functions
    [UART.c, main.c, read_RTC.c]
2020-05-27 Ostateczne pliki
    [HDD_L1.gbr, HDD_L2.gbr, HDD_NPTH.drl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]
2020-05-27 Added board outline
    [HDD_BRD.gbr]
2020-05-27 kolejne poprawki
    [HDD_L1.gbr, HDD_L2.gbr, HDD_PTH.drl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]
2020-06-20 działąjąca wersja
    [Hdd_Clock.sch]
